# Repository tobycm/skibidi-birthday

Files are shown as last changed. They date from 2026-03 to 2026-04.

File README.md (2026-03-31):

# skibidi-birthday

Happy birthday [Kai](https://github.com/KaiPereira)!! I wanted to put some FPGA footprint stuff but its too advanced for me lol. Hope you enjoy this card gift.

This is a USB 2.0 Hub, it doesn't need to have a case because the pcb itself is a birthday card, having a case would obviously hides the decorations and art on the pcb so it makes sense to not have a case designed.

[\[Blueprint\]](https://blueprint.hackclub.com/projects/13659) | [\[KiCanvas\]](https://kicanvas.org/?repo=https%3A%2F%2Fgithub.com%2Ftobycm%2Fskibidi-birthday%2Ftree%2Fmain%2Fpcb)

## PCB

2-Layer PCB, ENIG finish and white color with black silkscreen

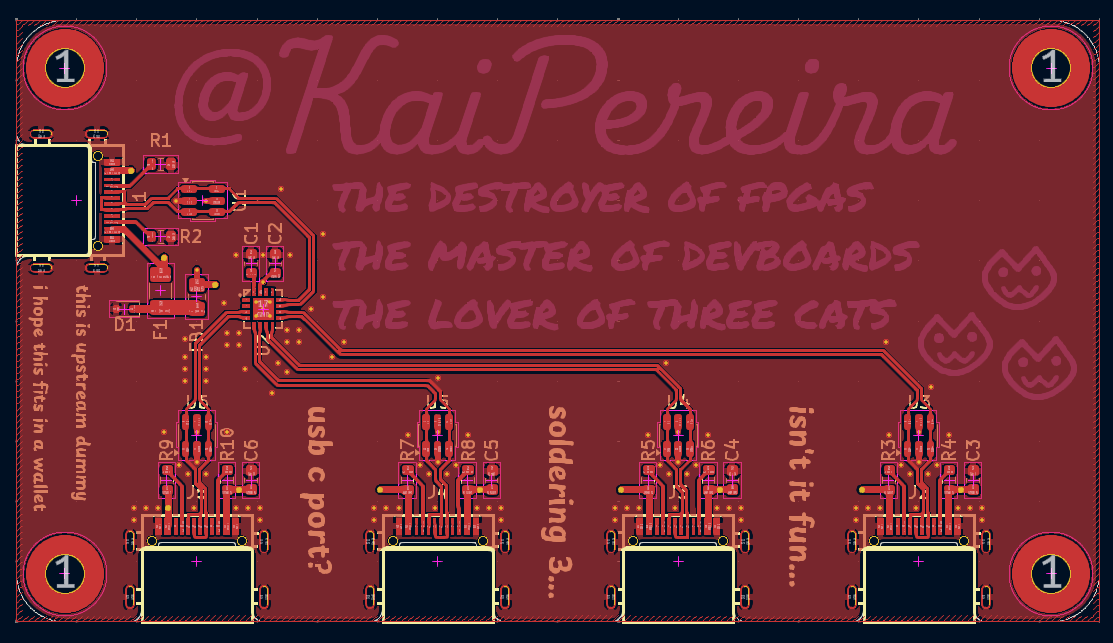
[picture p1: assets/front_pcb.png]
pcb front layer


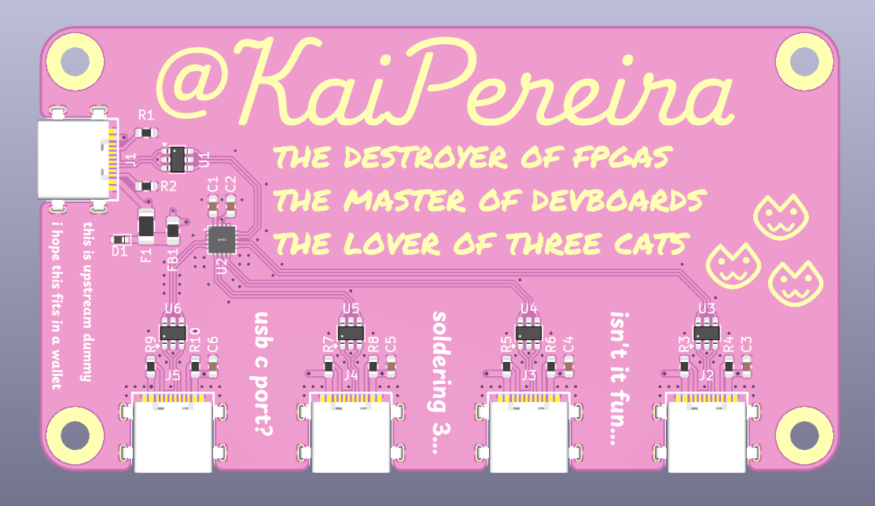
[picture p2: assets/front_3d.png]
pcb front 3d view


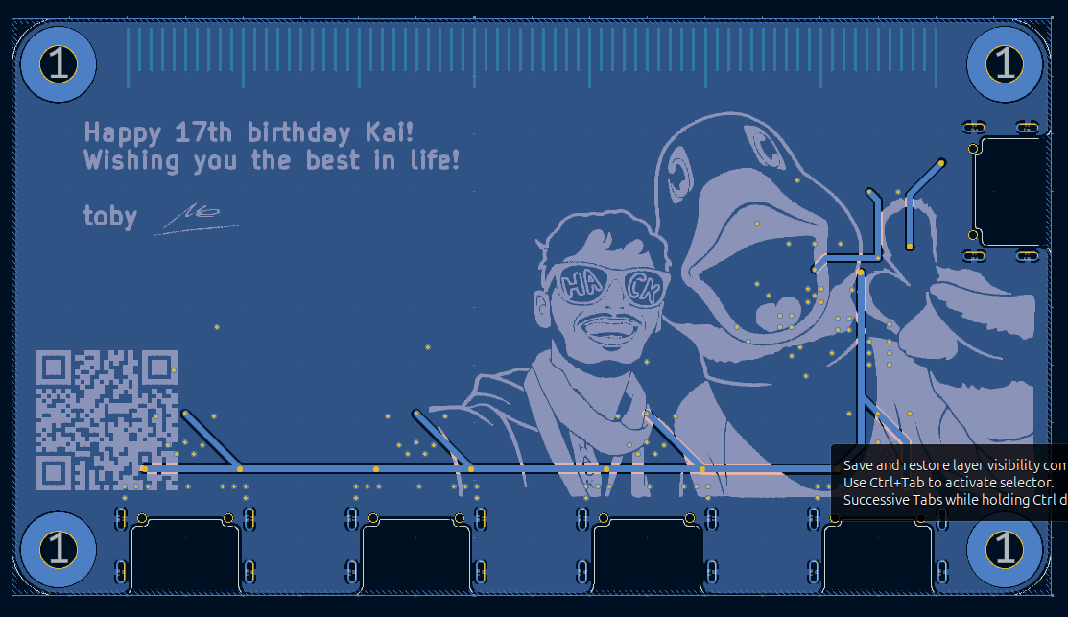
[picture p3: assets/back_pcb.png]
pcb back layer


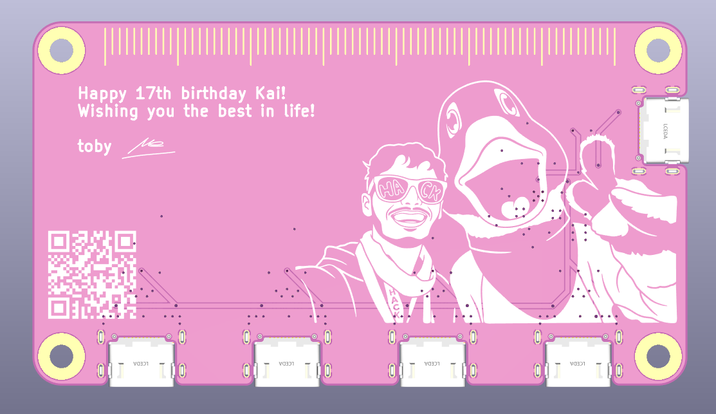
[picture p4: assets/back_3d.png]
pcb back 3d view


## Schematic

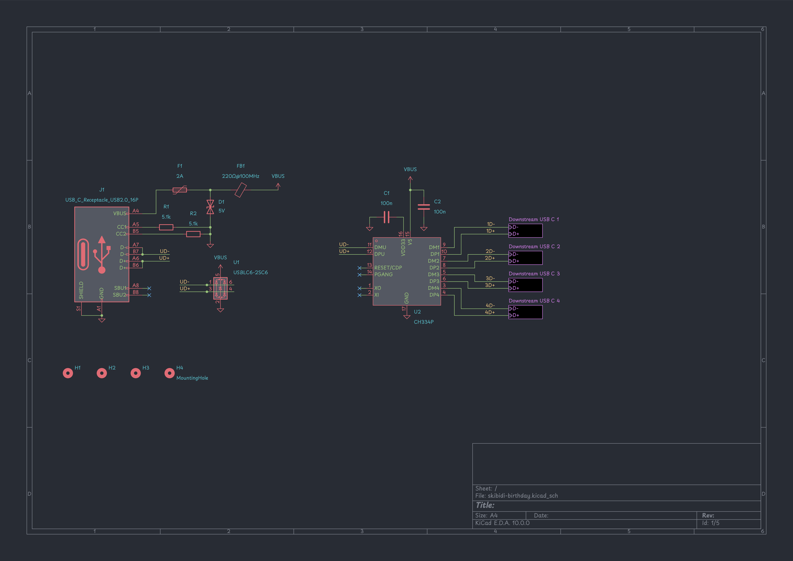
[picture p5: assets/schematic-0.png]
schematic page 1

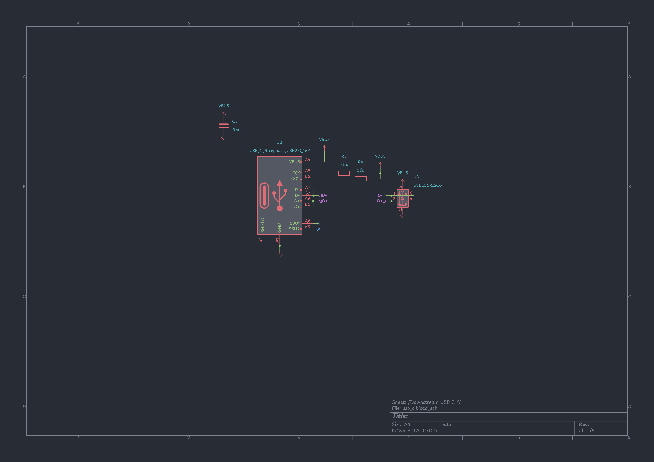
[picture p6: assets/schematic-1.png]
schematic page 2


# BOM

BOM is optimized for LCSC to help remove handling fee

| Description | Quantity | Part # | Unit Price | Extended Price (USD) | Product Link |
| :--- | :---: | :--- | :---: | :---: | :--- |
| 100nF ±10% 50V Ceramic Capacitor X7R 0603 | 100 | CL10B104KB8NNNC | 0.0028 | 0.28 | [Link](https://www.lcsc.com/product-detail/C1591.html) |
| 18.6VC Clamp 9.4A@8/20us Ipp ESD DIODE SOD-523 | 20 | ESD5Z5.0T1G | 0.0354 | 0.71 | [Link](https://www.lcsc.com/product-detail/C82044.html) |
| Polymeric PTC Resettable Fuse 12V 2A Surface Mount 1206 | 10 | BSMD1206-200-12V | 0.0616 | 0.62 | [Link](https://www.lcsc.com/product-detail/C883135.html) |
| 220Ω@100MHz 1 Line Ferrite Bead 0805 2A 45mΩ | 50 | BLM21PG221SN1D | 0.0229 | 1.15 | [Link](https://www.lcsc.com/product-detail/C85840.html) |
| USB-C (USB TYPE-C) Receptacle Connector 16 Position Surface Mount | 25 | TYPE-C-31-M-14 | 0.3534 | 8.84 | [Link](https://www.lcsc.com/product-detail/C223907.html) |
| 5.1kΩ ±1% 100mW 0603 Thick Film Resistor | 100 | FRC0603F5101TS | 0.0012 | 0.12 | [Link](https://www.lcsc.com/product-detail/C2907044.html) |
| 56kΩ ±1% 100mW 0603 Thick Film Resistor | 100 | 0603WAF5602T5E | 0.0013 | 0.13 | [Link](https://www.lcsc.com/product-detail/C23206.html) |
| 4 480Mbps USB 2.0 Hub QFN-16(3x3) Interface Controllers | 6 | CH334P | 0.4538 | 2.72 | [Link](https://www.lcsc.com/product-detail/C5373042.html) |
| 12VC Clamp 4.5A Ipp ESD DIODE SOT-23-6L | 40 | USBLC6-4SC6-ES | 0.0216 | 0.86 | [Link](https://www.lcsc.com/product-detail/C5180279.html) |
| **LCSC Shipping** | 1 | LCSC Shipping | 26.06 | 26.06 | [Link](https://www.lcsc.com/) |
| **2-Layer PCB** | 5 | PCB | 3.80 | 19.00 | [Link](https://jlcpcb.com/) |
| **Stencil** | 1 | Stencil | 3.05 | 3.05 | [Link](https://jlcpcb.com/) |
| **JLCPCB Shipping** | 1 | JLCPCB Shipping | 9.69 | 9.69 | [Link](https://jlcpcb.com/) |
| --- | --- | --- | --- | --- | --- |
| **Total** | | | | **$73.22** | |

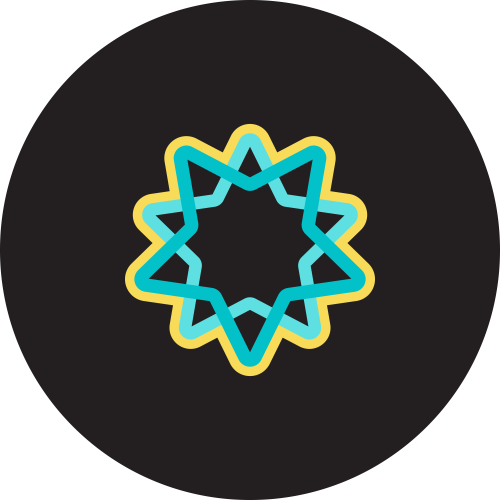
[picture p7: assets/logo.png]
 <a href="https://github.com/tobycm">tobycm</a>

This project was funded by [Blueprint](https://blueprint.hackclub.com/), a grant program by Hack Club that supports open source hardware projects for teenagers.

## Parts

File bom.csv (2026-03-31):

Description | Quantity | Part # | Unit price | Extended Price USD | Product Link
100nF ±10% 50V Ceramic Capacitor X7R 0603 | 100 | CL10B104KB8NNNC | 0.0028 | 0.28 | https://www.lcsc.com/product-detail/C1591.html
18.6VC Clamp 9.4A@8/20us Ipp ESD DIODE SOD-523 | 20 | ESD5Z5.0T1G | 0.0354 | 0.71 | https://www.lcsc.com/product-detail/C82044.html
Polymeric PTC Resettable Fuse 12V 2A Surface Mount 1206 | 10 | BSMD1206-200-12V | 0.0616 | 0.62 | https://www.lcsc.com/product-detail/C883135.html
220Ω@100MHz 1 Line Ferrite Bead 0805 2A 45mΩ | 50 | BLM21PG221SN1D | 0.0229 | 1.15 | https://www.lcsc.com/product-detail/C85840.html
USB-C (USB TYPE-C) Receptacle Connector 16 Position Surface Mount | 25 | TYPE-C-31-M-14 | 0.3534 | 8.84 | https://www.lcsc.com/product-detail/C223907.html
5.1kΩ ±1% 100mW 0603 Thick Film Resistor | 100 | FRC0603F5101TS | 0.0012 | 0.12 | https://www.lcsc.com/product-detail/C2907044.html
56kΩ ±1% 100mW 0603 Thick Film Resistor | 100 | 0603WAF5602T5E | 0.0013 | 0.13 | https://www.lcsc.com/product-detail/C23206.html
4 480Mbps USB 2.0 Hub QFN-16(3x3) Interface Controllers RoHS | 6 | CH334P | 0.4538 | 2.72 | https://www.lcsc.com/product-detail/C5373042.html
12VC Clamp 4.5A Ipp ESD DIODE SOT-23-6L | 40 | USBLC6-4SC6-ES | 0.0216 | 0.86 | https://www.lcsc.com/product-detail/C5180279.html
LCSC Shipping | 1 | LCSC Shipping | 26.06 | 26.06 | https://www.lcsc.com/
2-Layer PCB | 5 | PCB | 3.8 | 19.00 | https://jlcpcb.com/
Stencil | 1 | Stencil | 3.05 | 3.05 | https://jlcpcb.com/
JLCPCB Shipping | 1 | JLCPCB Shipping | 9.69 | 9.69 | https://jlcpcb.com/
 |  | Total: |  | 73.22

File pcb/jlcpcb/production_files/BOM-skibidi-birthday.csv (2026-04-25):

Comment | Designator | Footprint | LCSC | Quantity
100n | C1,C2 | C_0603_1608Metric | C1591 | 2
10u | C3,C4,C5,C6 | C_0603_1608Metric | C96446 | 4
220Ω@100MHz | FB1 | R_0805_2012Metric_Pad1.20x1.40mm_HandSolder | C85840 | 1
2A | F1 | Fuse_1206_3216Metric | C883135 | 1
5.1k | R1,R2 | R_0603_1608Metric | C2907044 | 2
56k | R10,R3,R4,R5,R6,R7,R8,R9 | R_0603_1608Metric | C23206 | 8
5V | D1 | D_SOD-523 | C82044 | 1
CH334P | U2 | QFN-16_L3.0-W3.0-P0.50-BL-EP1.7 | C5373042 | 1
USBLC6-2SC6 | U1,U3,U4,U5,U6 | SOT-23-6 | C2827654 | 5
USB_C_Receptacle_USB2.0_16P | J1,J2,J3,J4,J5 | USB-C-SMD_12P-P0.50-H-F_TYPE-C-31-M-14 | C223907 | 5

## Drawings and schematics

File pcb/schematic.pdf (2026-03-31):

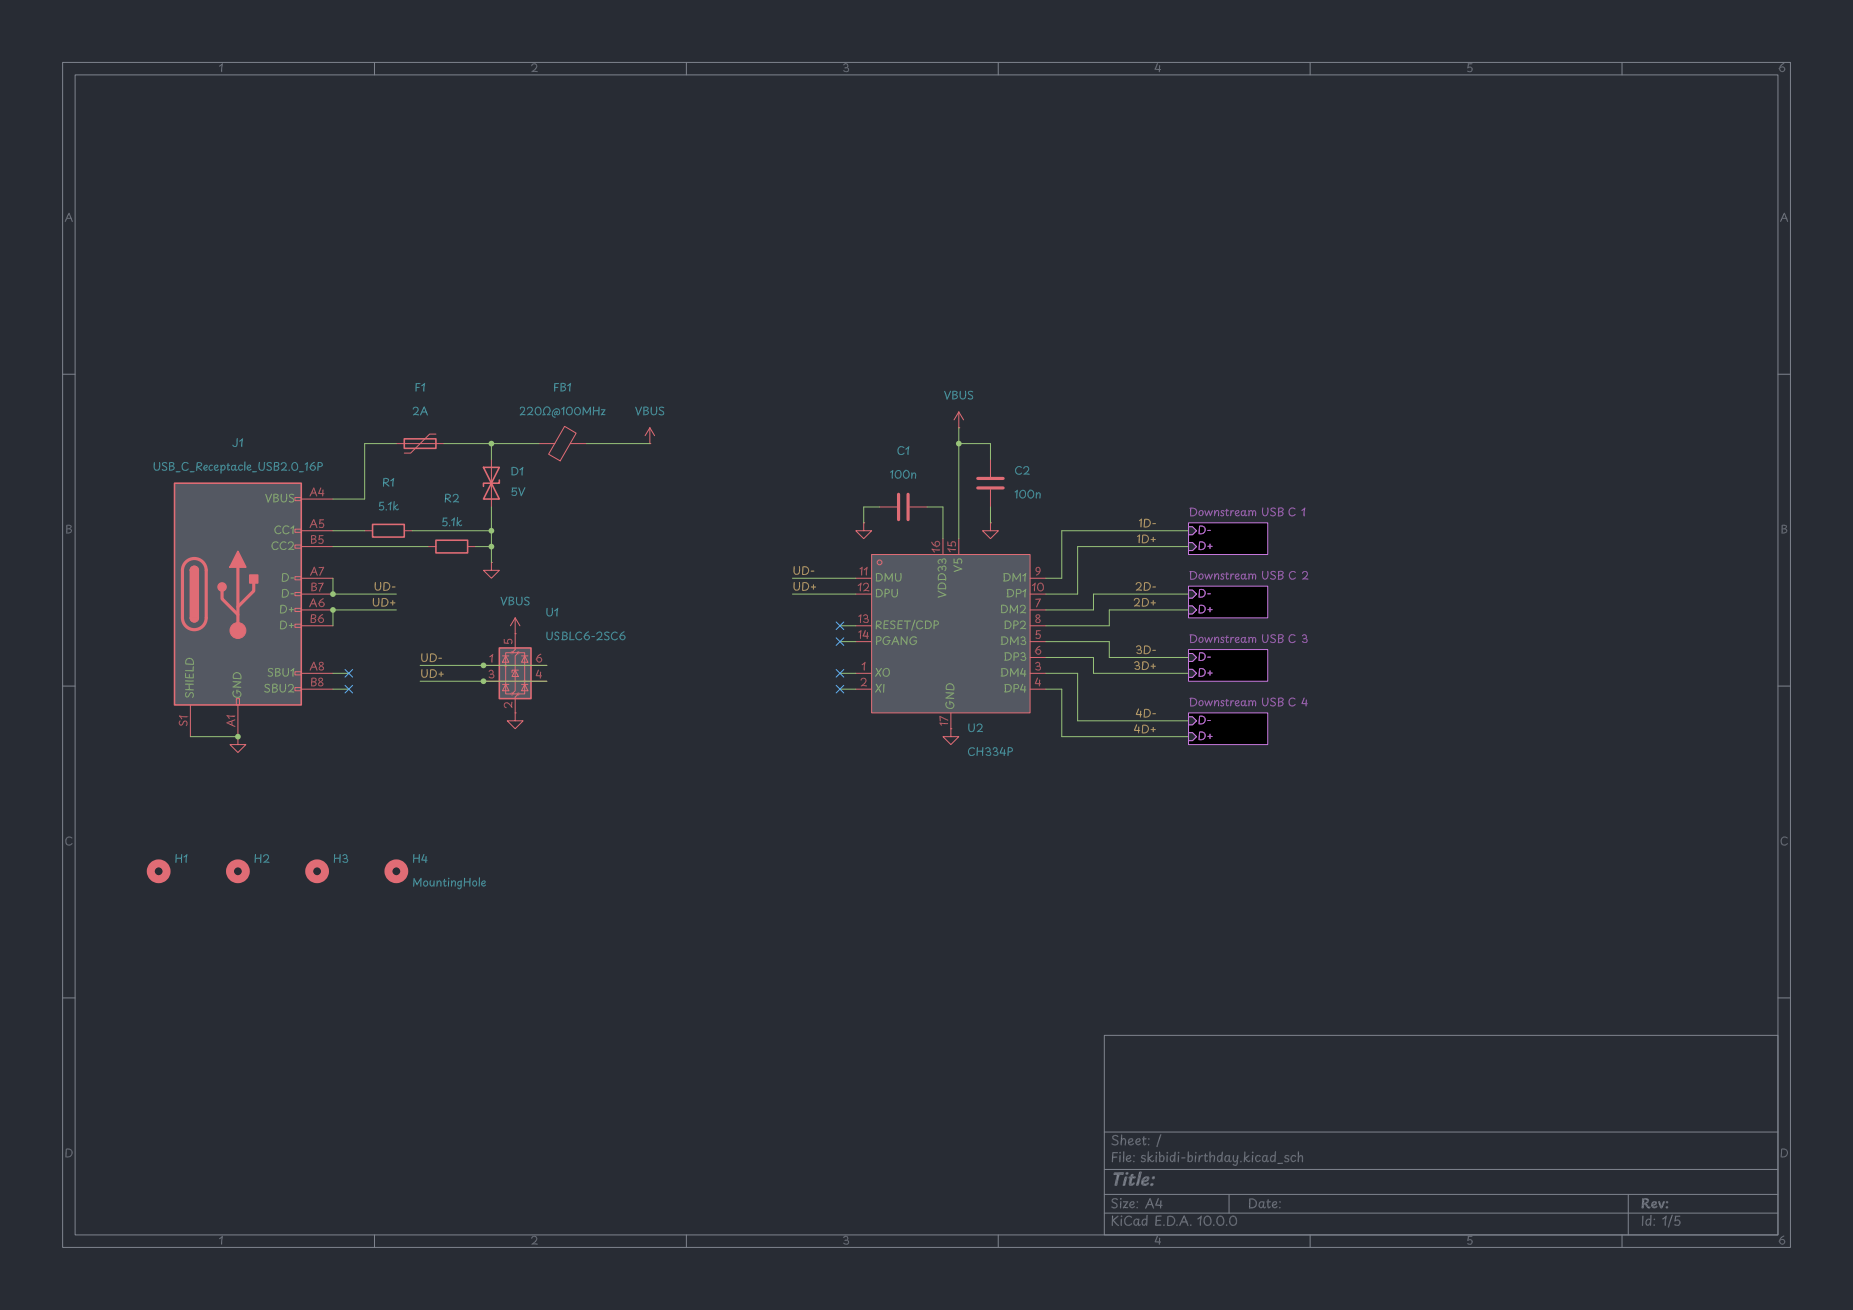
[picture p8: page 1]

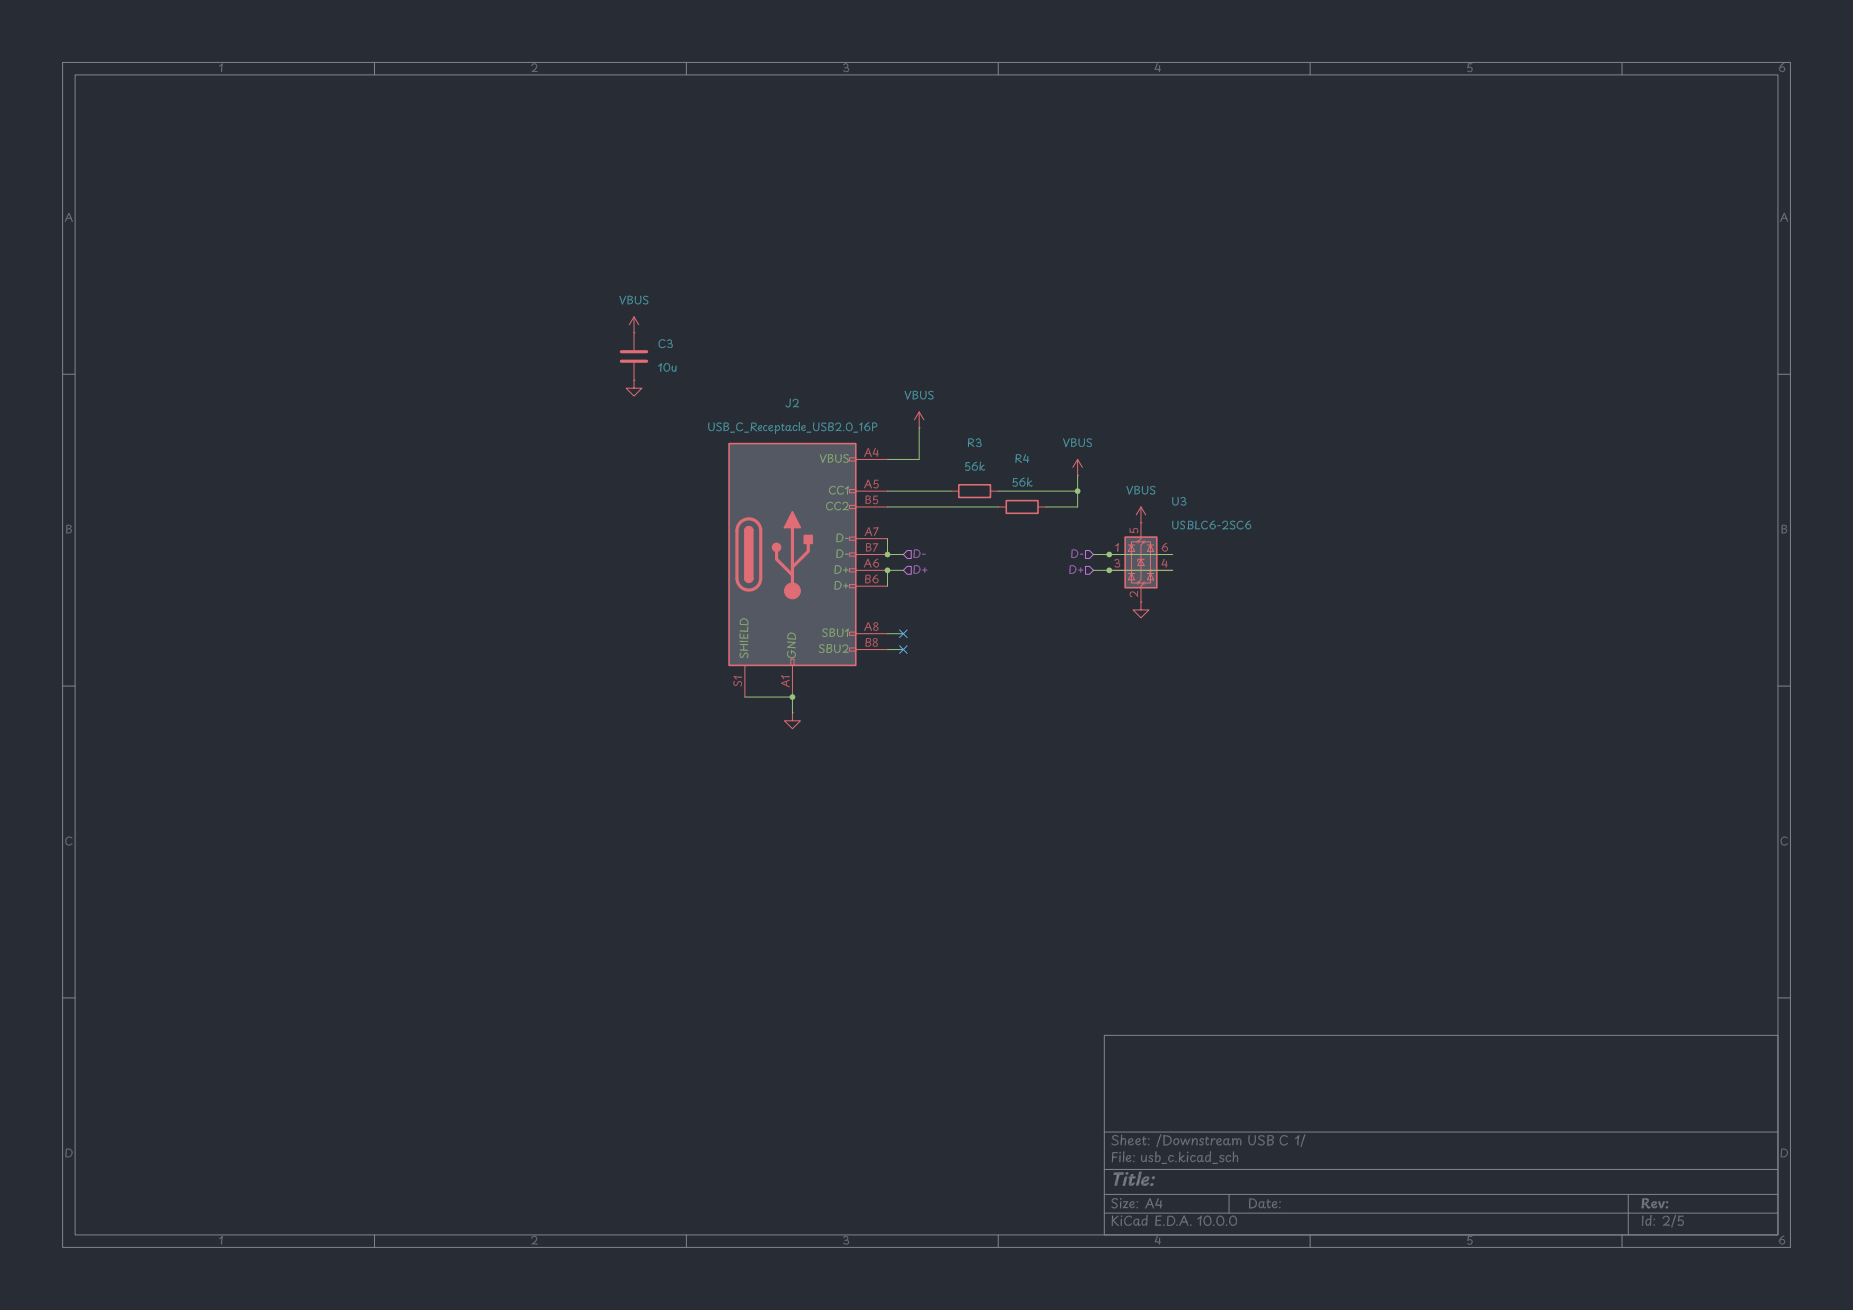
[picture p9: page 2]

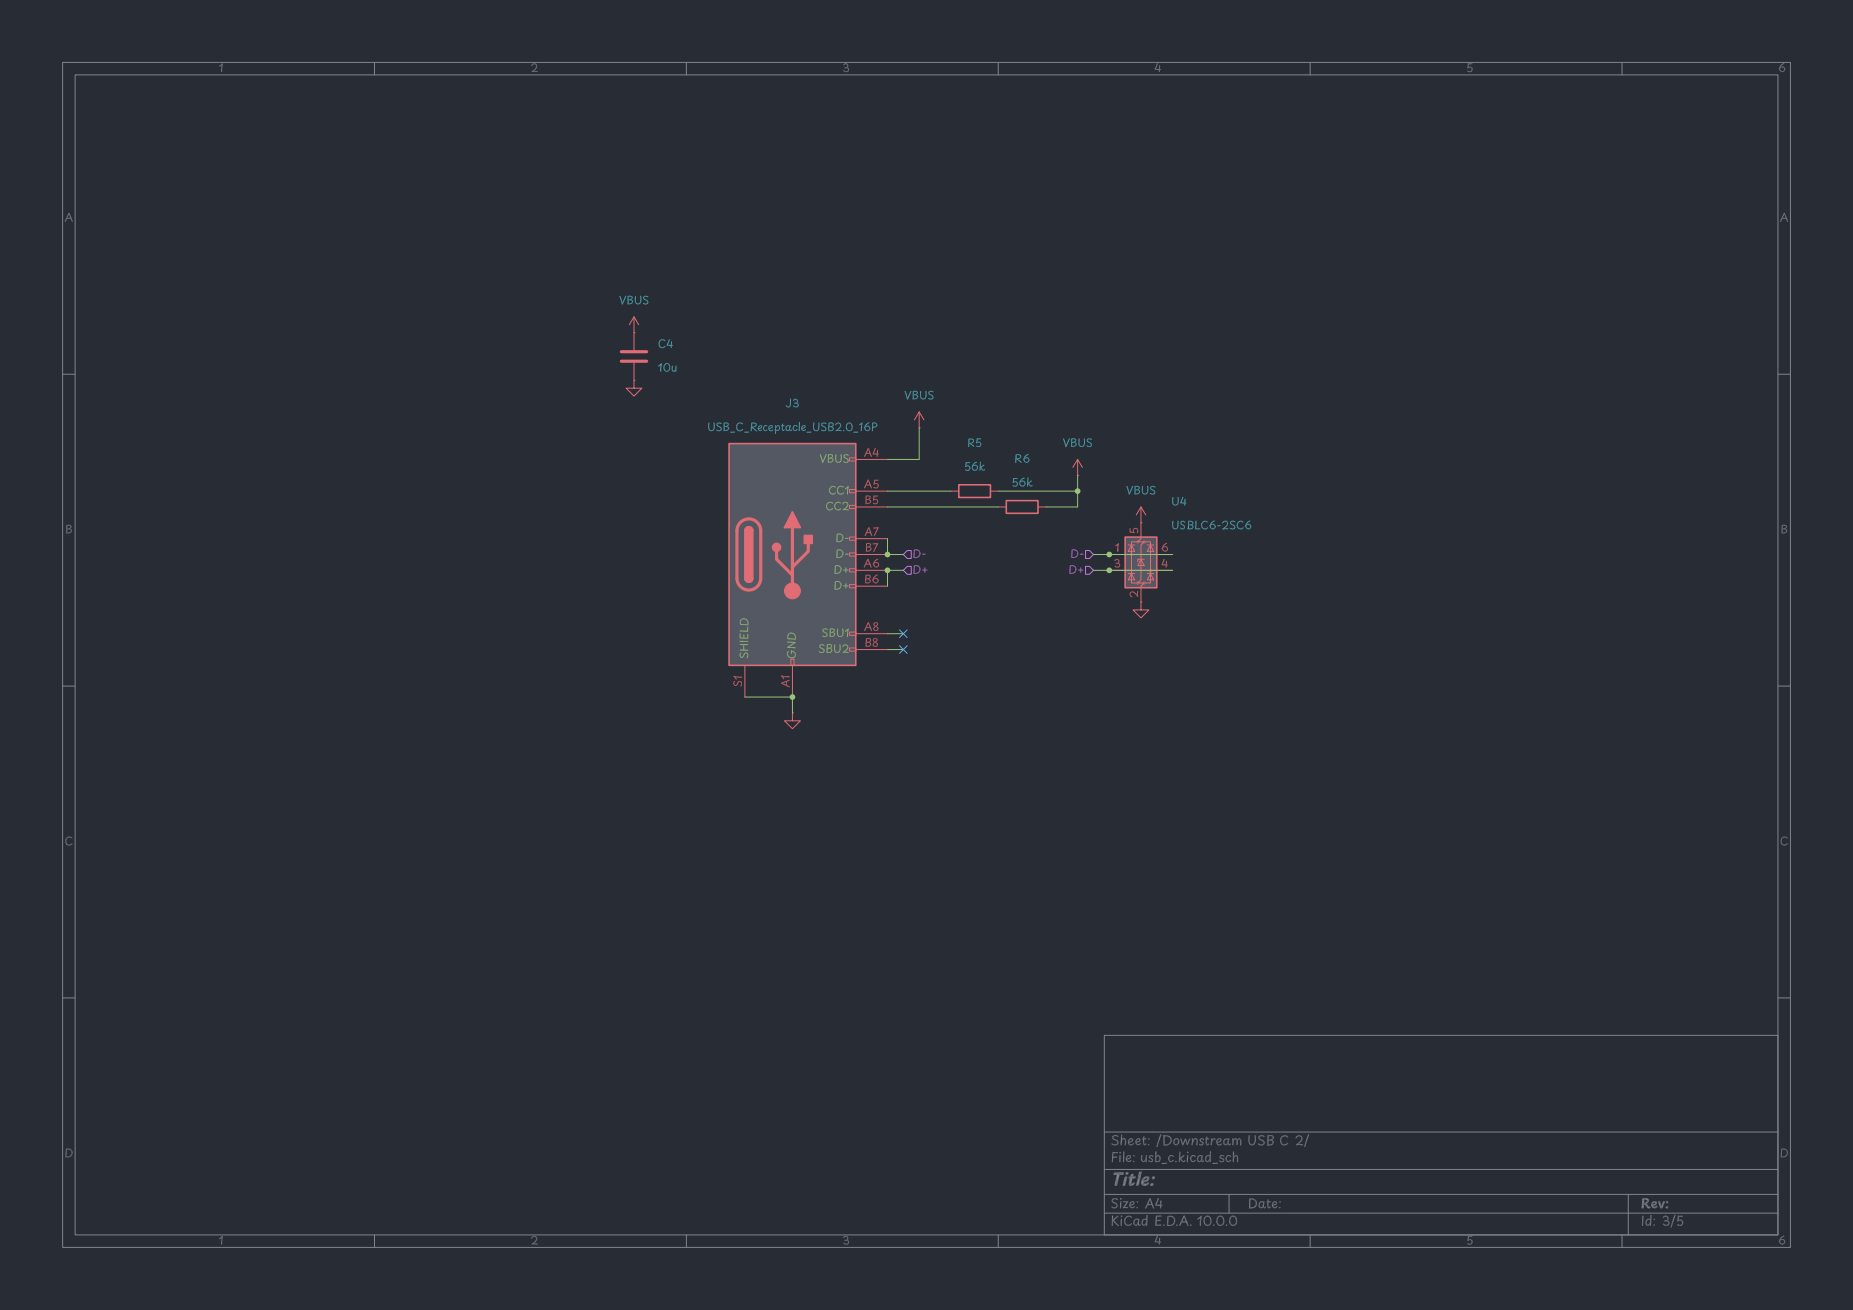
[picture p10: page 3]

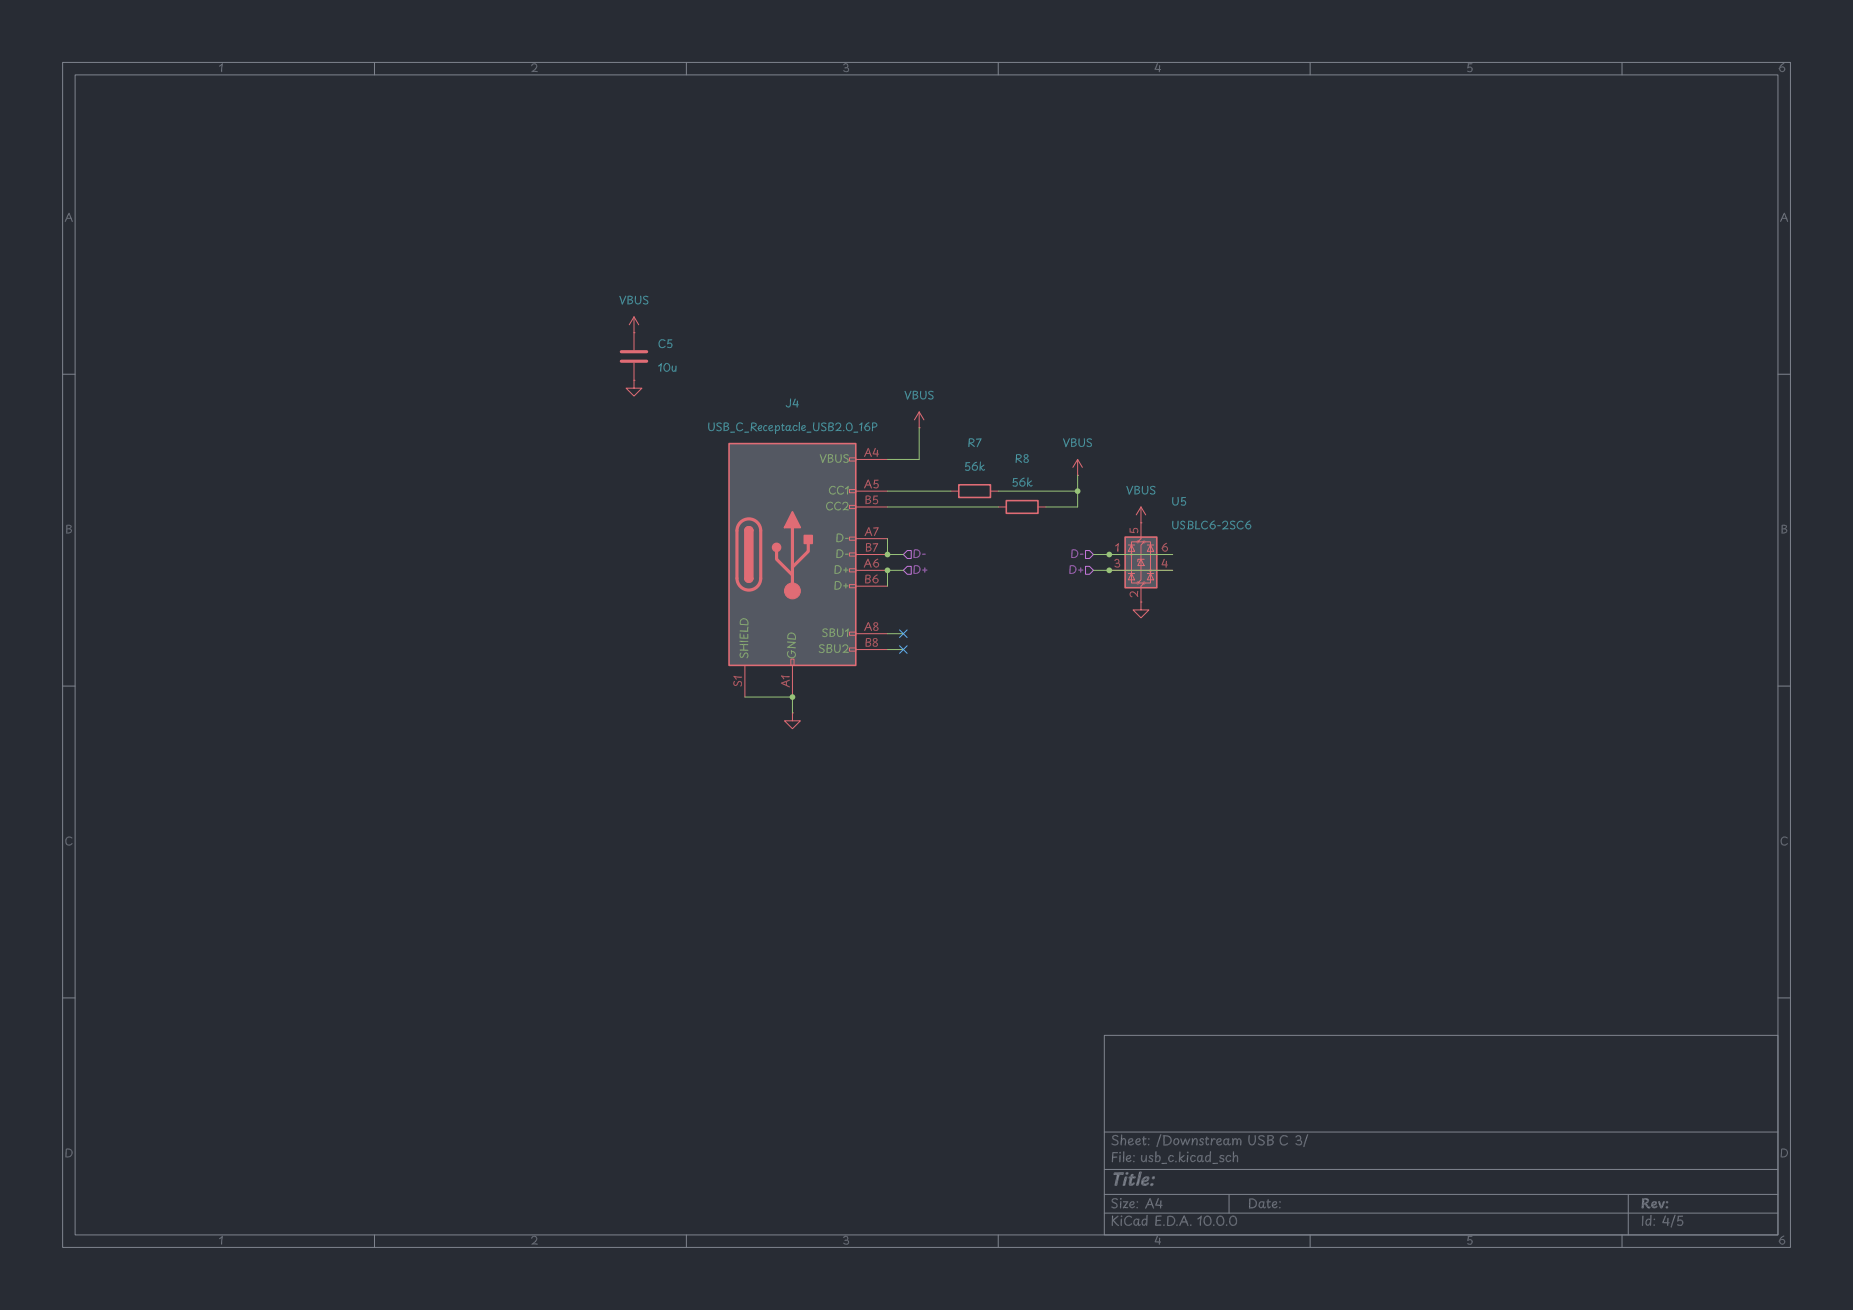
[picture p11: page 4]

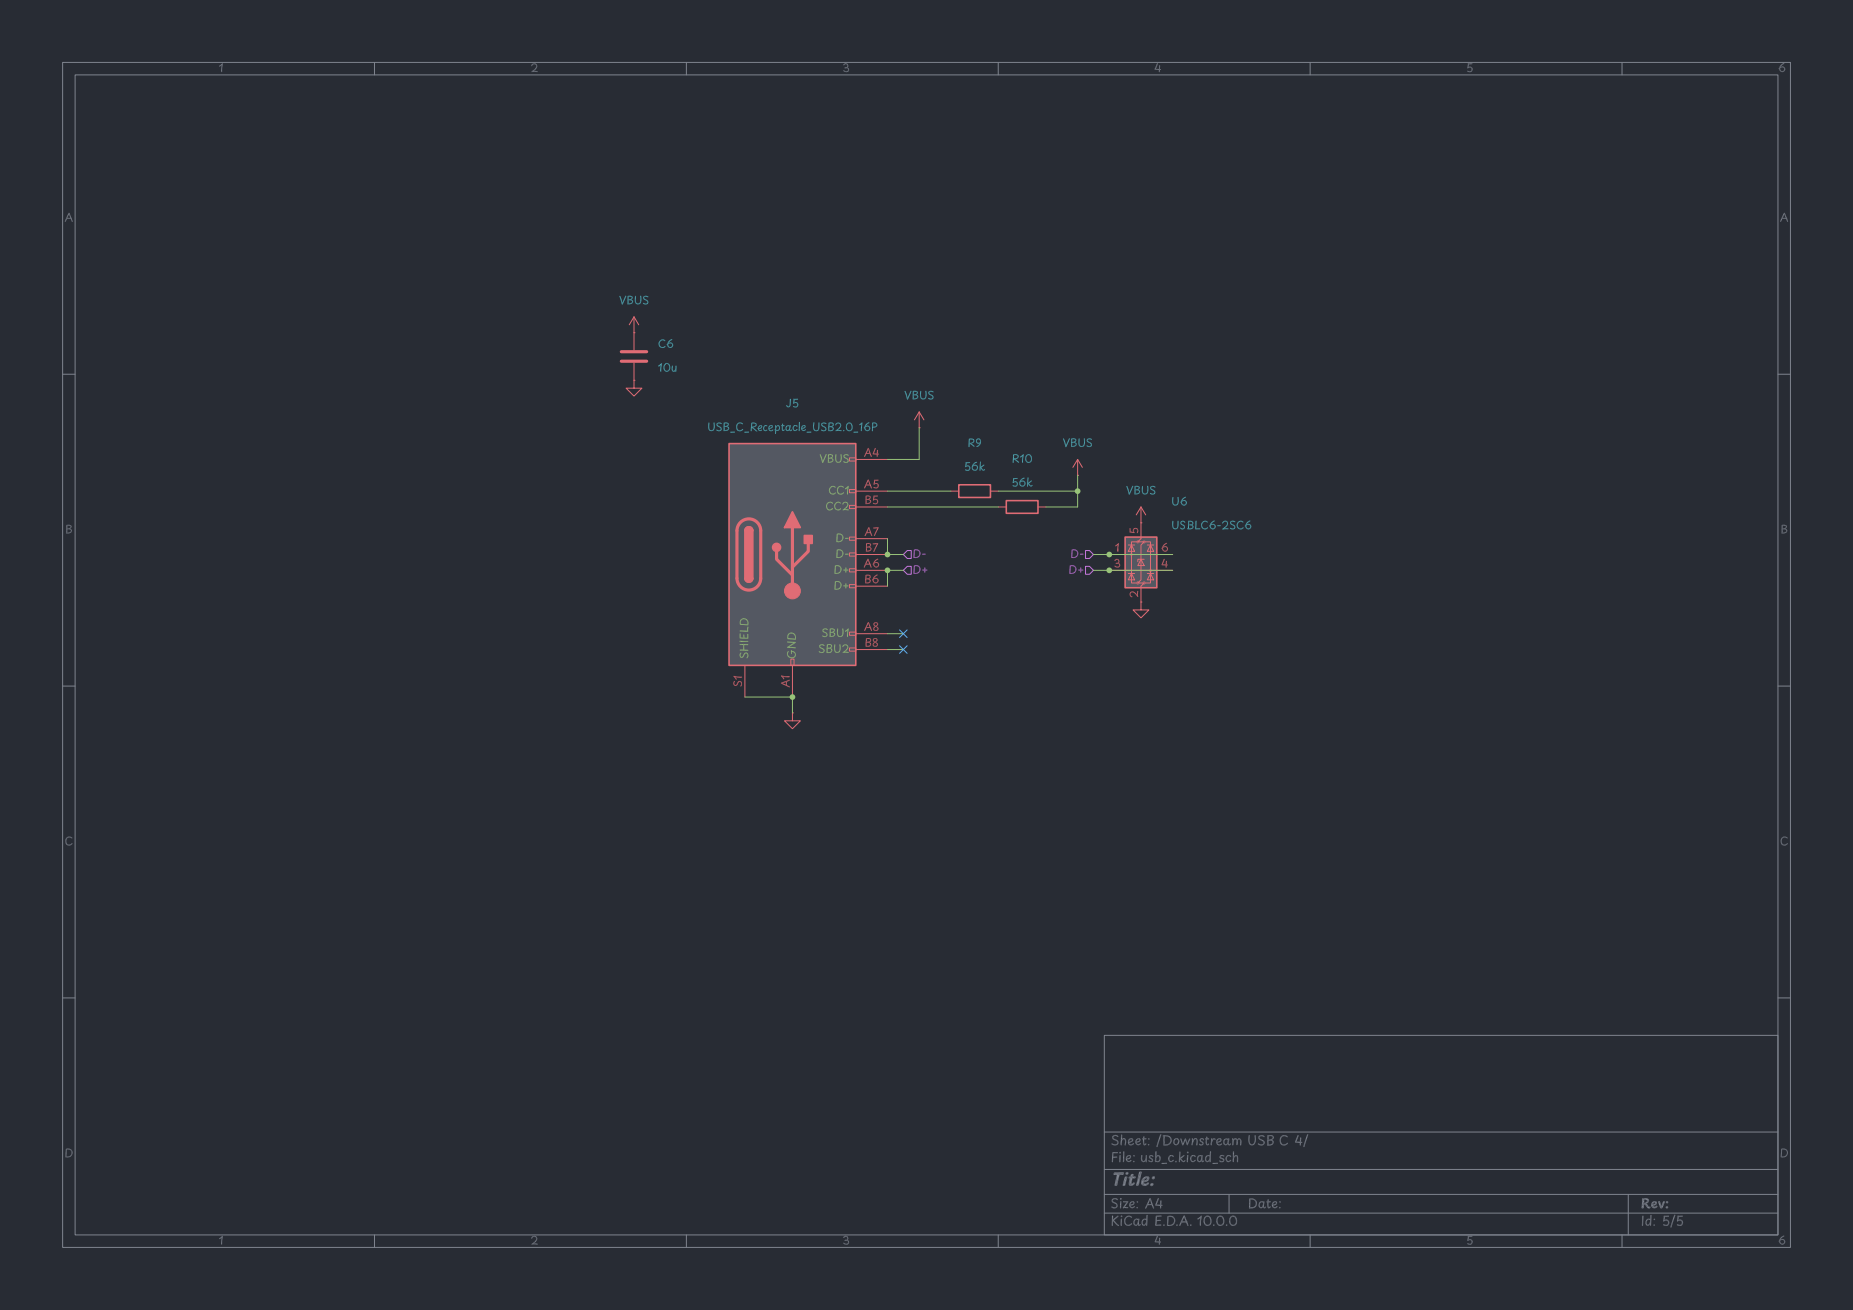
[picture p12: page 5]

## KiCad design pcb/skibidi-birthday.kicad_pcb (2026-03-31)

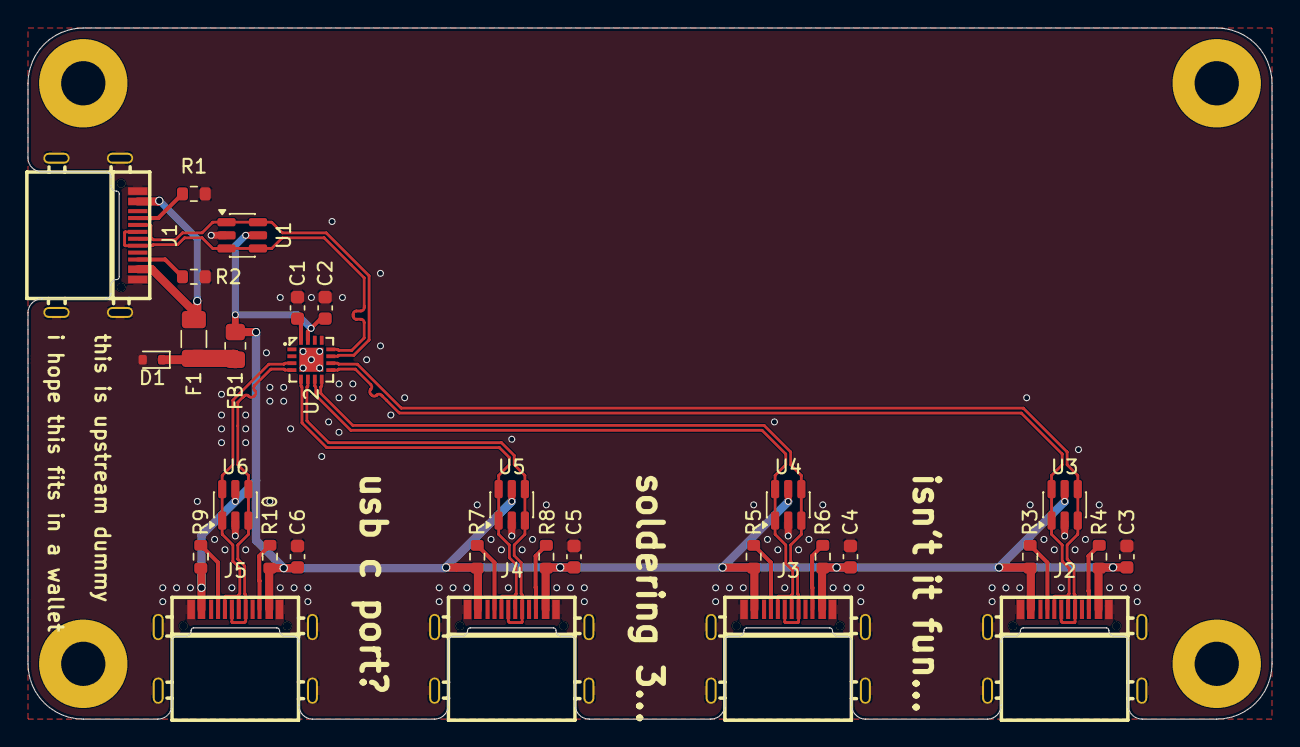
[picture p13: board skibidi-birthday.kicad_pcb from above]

Board: 2 copper layers, 90.0 x 50.0 mm, 34 parts (0 on the bottom side), 25 nets.

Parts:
C1, C2: 100n; C_0603_1608Metric
C3, C4, C5, C6: 10u; C_0603_1608Metric
D1: 5V; D_SOD-523
F1: 2A; Fuse_1206_3216Metric
FB1: 220Ω@100MHz; R_0805_2012Metric_Pad1.20x1.40mm_HandSolder
H1, H2, H3, H4: MountingHole; MountingHole_3.2mm_M3_Pad
J1, J2, J3, J4, J5: USB_C_Receptacle_USB2.0_16P; USB-C-SMD_12P-P0.50-H-F_TYPE-C-31-M-14
R1, R2: 5.1k; R_0603_1608Metric
R3, R4, R5, R6, R7, R8, R9, R10: 56k; R_0603_1608Metric
U1, U3, U4, U5, U6: USBLC6-2SC6; SOT-23-6
U2: CH334P; QFN-16_L3.0-W3.0-P0.50-BL-EP1.7

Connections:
/1D+: J2.A6 (D+), J2.B6 (D+), U2.10 (DP1), U3.3 (I/O2), U3.4 (I/O2)
/1D-: J2.A7 (D-), J2.B7 (D-), U2.9 (DM1), U3.1 (I/O1), U3.6 (I/O1)
/2D+: J3.A6 (D+), J3.B6 (D+), U2.8 (DP2), U4.3 (I/O2), U4.4 (I/O2)
/2D-: J3.A7 (D-), J3.B7 (D-), U2.7 (DM2), U4.1 (I/O1), U4.6 (I/O1)
/3D+: J4.A6 (D+), J4.B6 (D+), U2.6 (DP3), U5.3 (I/O2), U5.4 (I/O2)
/3D-: J4.A7 (D-), J4.B7 (D-), U2.5 (DM3), U5.1 (I/O1), U5.6 (I/O1)
/4D+: J5.A6 (D+), J5.B6 (D+), U2.4 (DP4), U6.3 (I/O2), U6.4 (I/O2)
/4D-: J5.A7 (D-), J5.B7 (D-), U2.3 (DM4), U6.1 (I/O1), U6.6 (I/O1)
/UD+: J1.A6 (D+), J1.B6 (D+), U1.3 (I/O2), U1.4 (I/O2), U2.12 (DPU)
/UD-: J1.A7 (D-), J1.B7 (D-), U1.1 (I/O1), U1.6 (I/O1), U2.11 (DMU)
GND: C1.2, C2.1, C3.2, C4.2, C5.2, C6.2, D1.2 (A2), J1.A1 (GND), J1.B1 (GND), J1.S1 (SHIELD), J2.A1 (GND), J2.B1 (GND), J2.S1 (SHIELD), J3.A1 (GND), J3.B1 (GND), J3.S1 (SHIELD), J4.A1 (GND), J4.B1 (GND), J4.S1 (SHIELD), J5.A1 (GND), J5.B1 (GND), J5.S1 (SHIELD), R1.2, R2.2, U1.2 (GND), U2.17 (GND), U3.2 (GND), U4.2 (GND), U5.2 (GND), U6.2 (GND)
unnamed: D1.1 (A1), F1.2, FB1.1
unnamed: F1.1, J1.A4 (VBUS), J1.B4 (VBUS)
unnamed: J1.A5 (CC1), R1.1
unnamed: J1.B5 (CC2), R2.1
unnamed: J2.A5 (CC1), R3.2
unnamed: J2.B5 (CC2), R4.2
unnamed: J3.A5 (CC1), R5.2
unnamed: J3.B5 (CC2), R6.2
unnamed: J4.A5 (CC1), R7.2
unnamed: J4.B5 (CC2), R8.2
unnamed: J5.A5 (CC1), R9.2
unnamed: J5.B5 (CC2), R10.2
unnamed: C1.1, U2.16 (VDD33)
VBUS: C2.2, C3.1, C4.1, C5.1, C6.1, FB1.2, J2.A4 (VBUS), J2.B4 (VBUS), J3.A4 (VBUS), J3.B4 (VBUS), J4.A4 (VBUS), J4.B4 (VBUS), J5.A4 (VBUS), J5.B4 (VBUS), R3.1, R4.1, R5.1, R6.1, R7.1, R8.1, R9.1, R10.1, U1.5 (VBUS), U2.15 (V5), U3.5 (VBUS), U4.5 (VBUS), U5.5 (VBUS), U6.5 (VBUS)

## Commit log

2026-03-31 forgor to commit... so here's a big one
    [BOM-skibidi-birthday.csv, skibidi-birthday.kicad_pcb, skibidi-birthday.kicad_sch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]
2026-03-31 add bom
    [bom.csv]
2026-03-31 forgot to length match for the 67th time
    [skibidi-birthday.kicad_pcb]
2026-04-25 update bom and cpl
    [BOM-skibidi-birthday.csv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]
